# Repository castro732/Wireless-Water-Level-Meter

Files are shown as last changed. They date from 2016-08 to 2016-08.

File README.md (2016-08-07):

#Wireless Water Level Meter

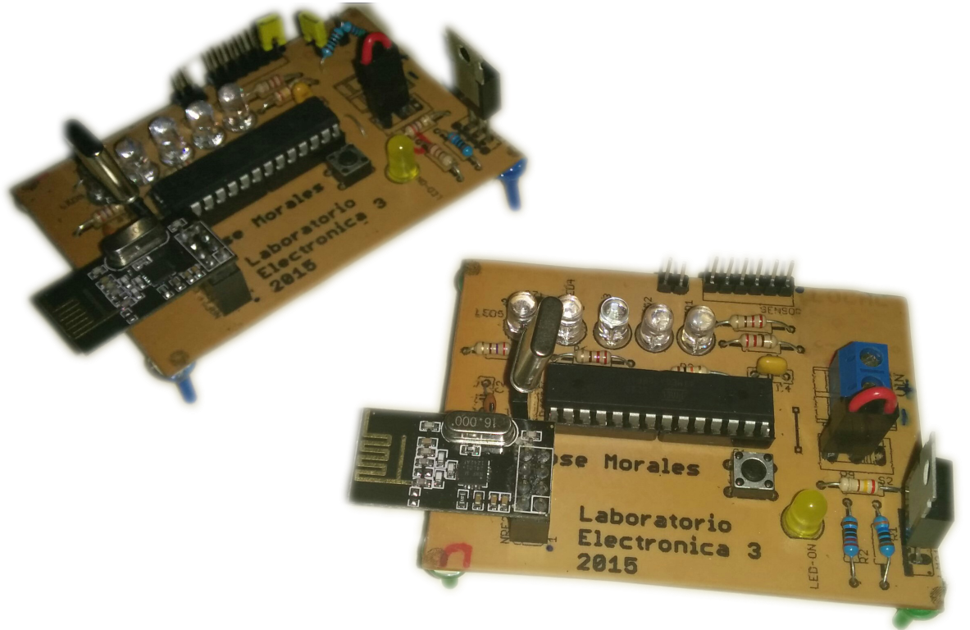
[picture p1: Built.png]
Built modules


##Description

System for measuring the water level in a tank using a current loop (4 mA to 20 mA) wirelessly.

The system consists of 2 modules, a local module and a remote module.
	The local module reads the level of water and transmits it to the remote module (using nRF24L0).
	The remote receives the data and displays it using 5 LEDs, corresponding to the 5 levels of water, from empty to full.

##Features
- Wireless, using nRF24L0.
- Programmed via Arduino using an Atmega328P.
- LEDs indicating the level of water in both modules (local and remote).
- Powered with 5V via screw terminals.
- Programming headers (serial) to facilitate the reprogramming of the microcontrollers.
	- Programs using an Arduino.

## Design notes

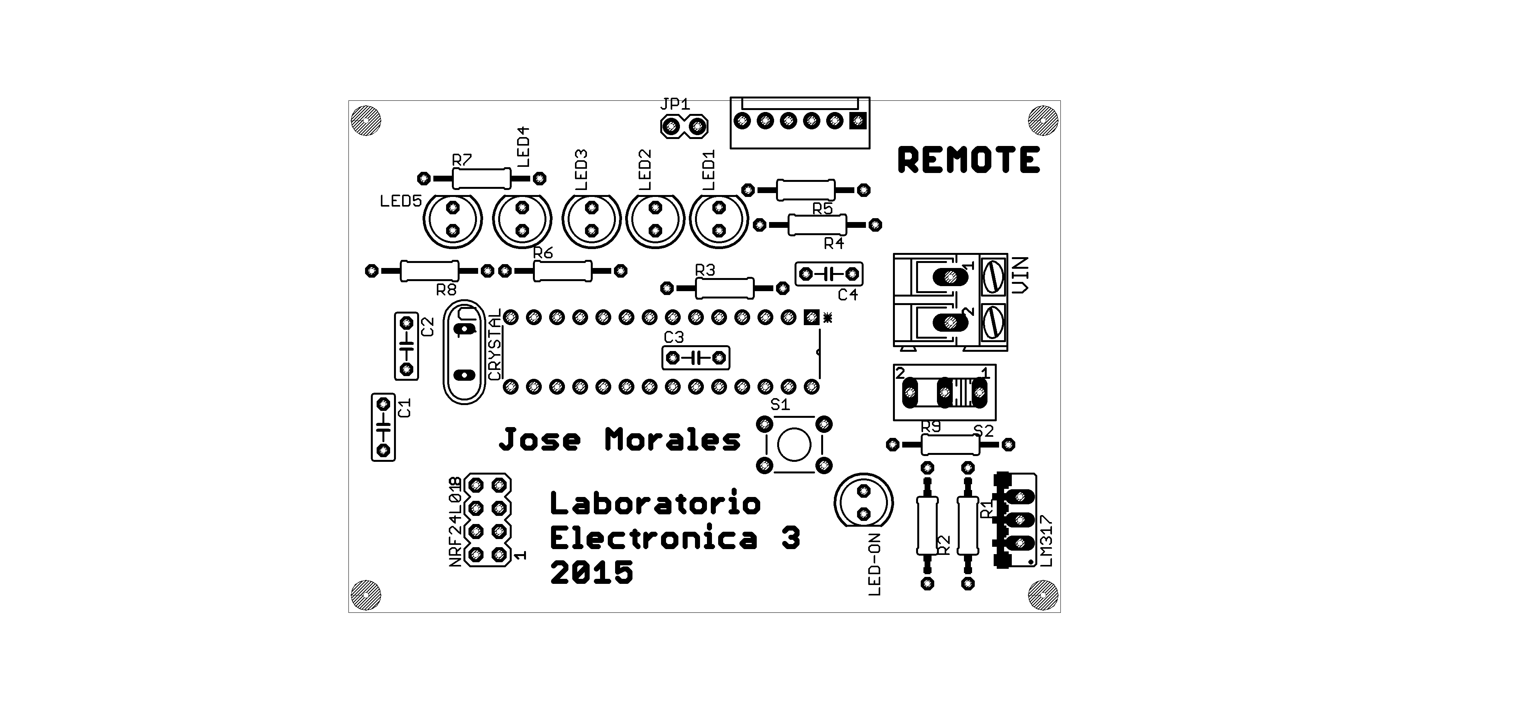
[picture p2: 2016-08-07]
remote_top.png

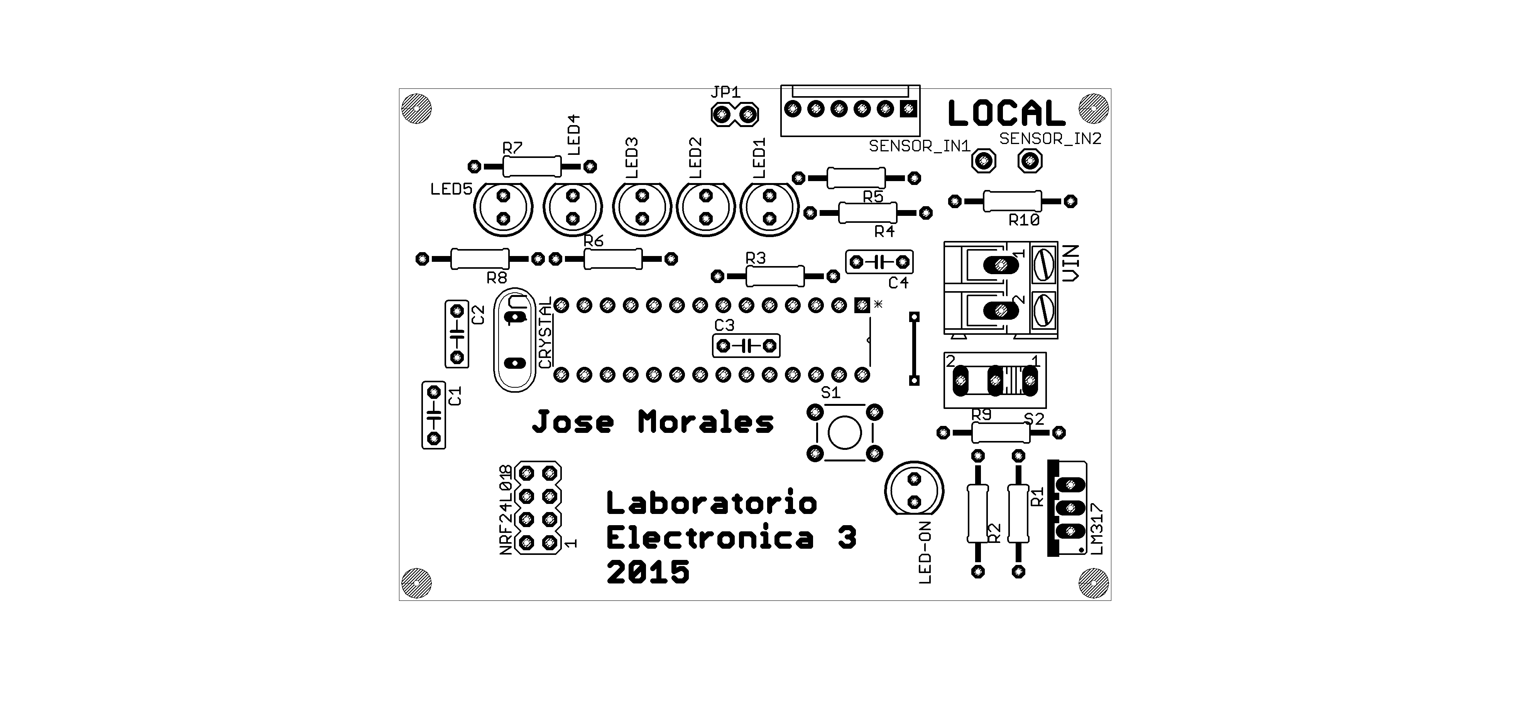
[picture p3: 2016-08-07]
local_top.png

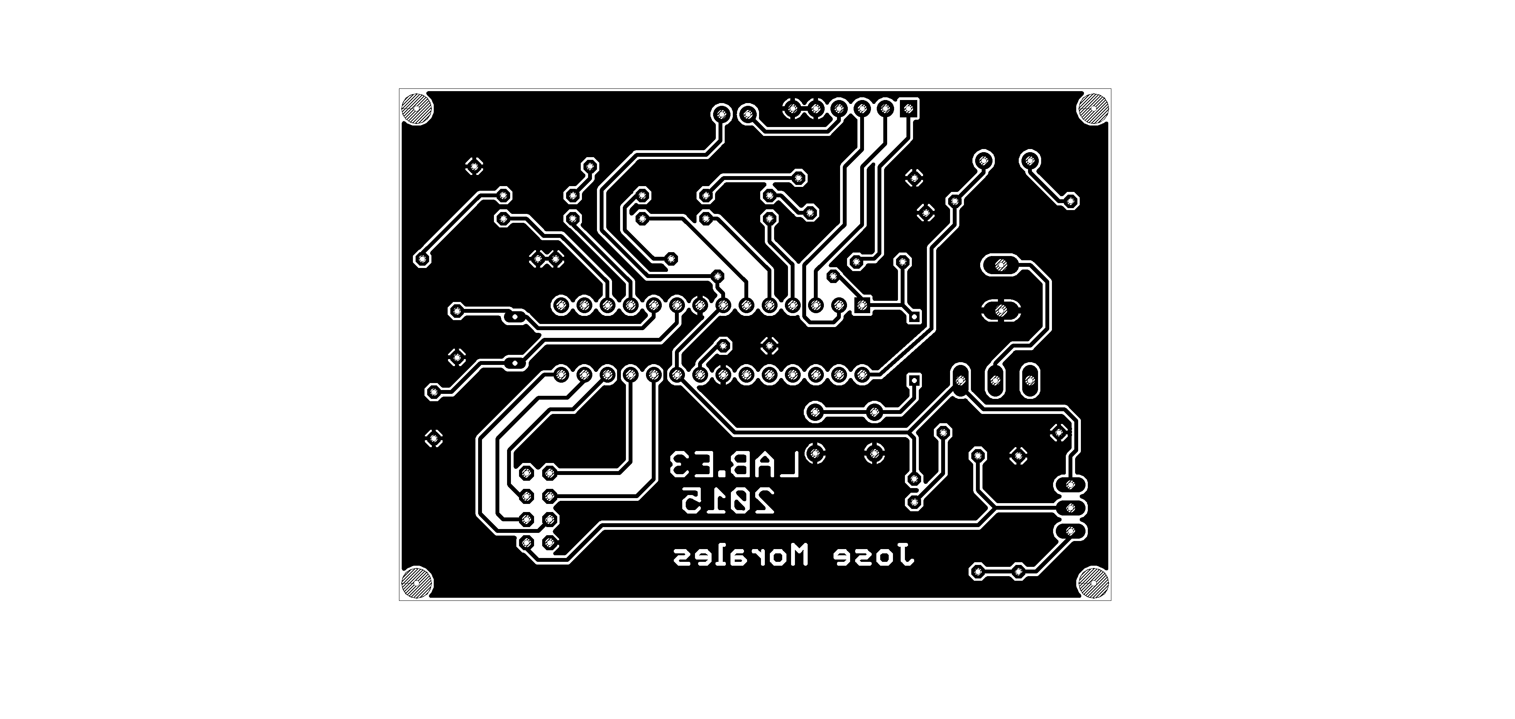
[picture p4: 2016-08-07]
local_bot.png

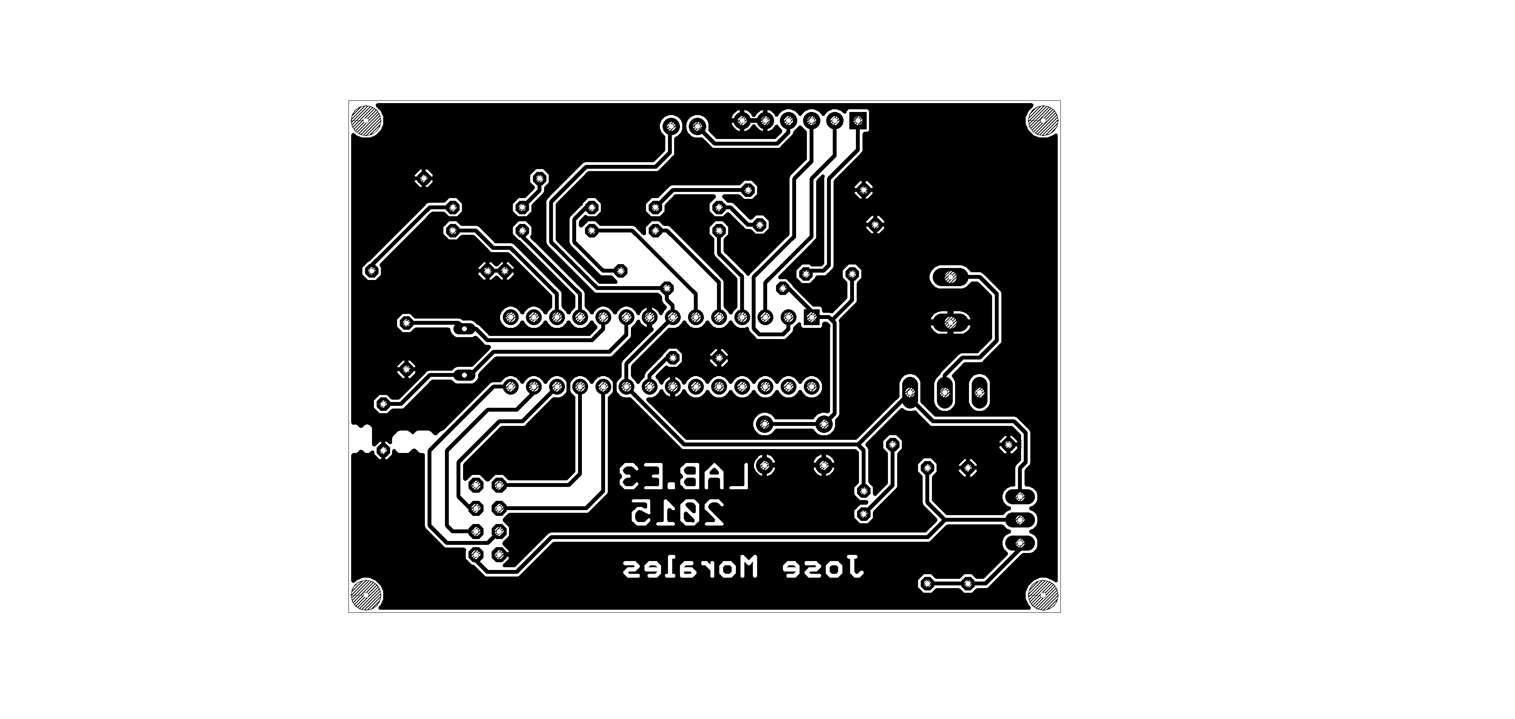
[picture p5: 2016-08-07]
remote_bot.png

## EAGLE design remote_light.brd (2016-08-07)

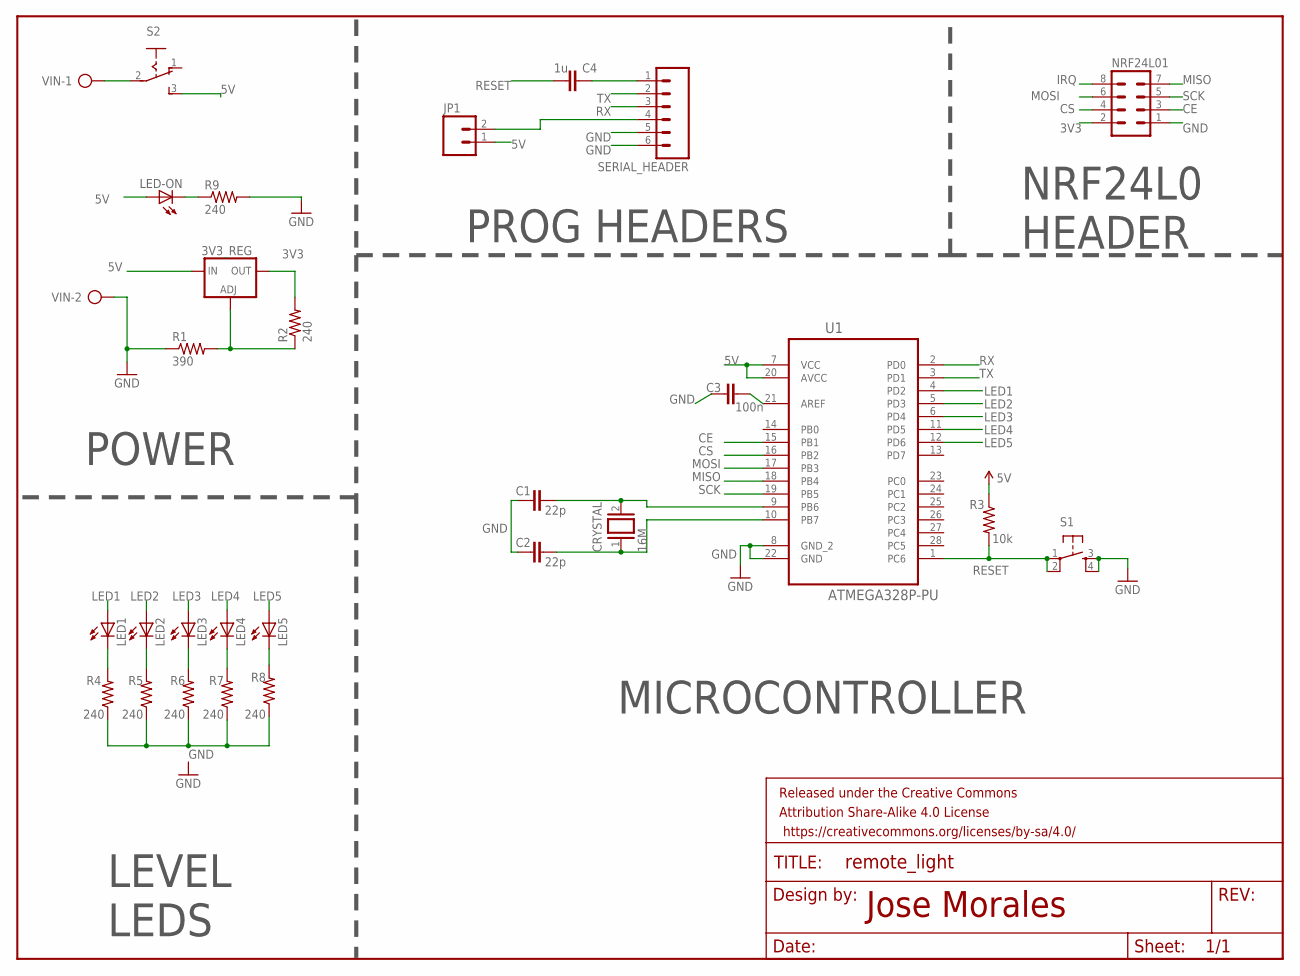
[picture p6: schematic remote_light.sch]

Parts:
C1, C2: 22p; C050-025X075
C3: 100n; C050-025X075
C4: 1u; C050-025X075
CRYSTAL: 16M; QS
FRAME11: FRAME-LETTER; CREATIVE_COMMONS
JP1: M02LOCK; 1X02_LOCK
LED1, LED2, LED3, LED4, LED5: LED5MM
LED-ON: LED5MM
LM317: 3V3_REG; 317TS
NRF24L01: MA04-2
R1: 390; 0207/12
R2, R4, R5, R6, R7, R8, R9: 240; 0207/12
R3: 10k; 0207/12
S1: TAC_SWITCHPTH; TACTILE-PTH
S2: 255SB
SERIAL_HEADER: M06POLAR; MOLEX-1X6
U1: ATMEGA328P-PU; DIP254P762X457-28
VIN: AK300/2

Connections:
3V3: LM317.2 (OUT), NRF24L01.2, R2.2
5V: JP1.1, LED-ON.A, LM317.3 (IN), R3.1, S2.3 (S), U1.7 (VCC), U1.20 (AVCC)
CE: NRF24L01.3, U1.15 (PB1)
CS: NRF24L01.4, U1.16 (PB2)
GND: C1.2, C2.2, C3.2, NRF24L01.1, R1.1, R4.1, R5.1, R6.1, R7.1, R8.1, R9.2, S1.3, S1.4, SERIAL_HEADER.5, SERIAL_HEADER.6, U1.8 (GND_2), U1.22 (GND), VIN.2
IRQ: NRF24L01.8
LED1: LED1.A, U1.4 (PD2)
LED2: LED2.A, U1.5 (PD3)
LED3: LED3.A, U1.6 (PD4)
LED4: LED4.A, U1.11 (PD5)
LED5: LED5.A, U1.12 (PD6)
MISO: NRF24L01.7, U1.18 (PB4)
MOSI: NRF24L01.6, U1.17 (PB3)
unnamed: LM317.1 (ADJ), R1.2, R2.1
unnamed: C1.1, CRYSTAL.2, U1.9 (PB6)
unnamed: LED1.K (C), R4.2
unnamed: LED-ON.K (C), R9.1
unnamed: C2.1, CRYSTAL.1, U1.10 (PB7)
unnamed: LED2.K (C), R5.2
unnamed: LED3.K (C), R6.2
unnamed: LED4.K (C), R7.2
unnamed: LED5.K (C), R8.2
unnamed: C3.1, U1.21 (AREF)
unnamed: C4.2, SERIAL_HEADER.1
unnamed: S2.2, VIN.1
unnamed: JP1.2, SERIAL_HEADER.4
RESET: C4.1, R3.2, S1.1, S1.2, U1.1 (PC6)
RX: SERIAL_HEADER.3, U1.2 (PD0)
SCK: NRF24L01.5, U1.19 (PB5)
TX: SERIAL_HEADER.2, U1.3 (PD1)

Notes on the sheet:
Jose Morales
POWER
PROG HEADERS
NRF24L0 HEADER
LEVEL LEDS
MICROCONTROLLER

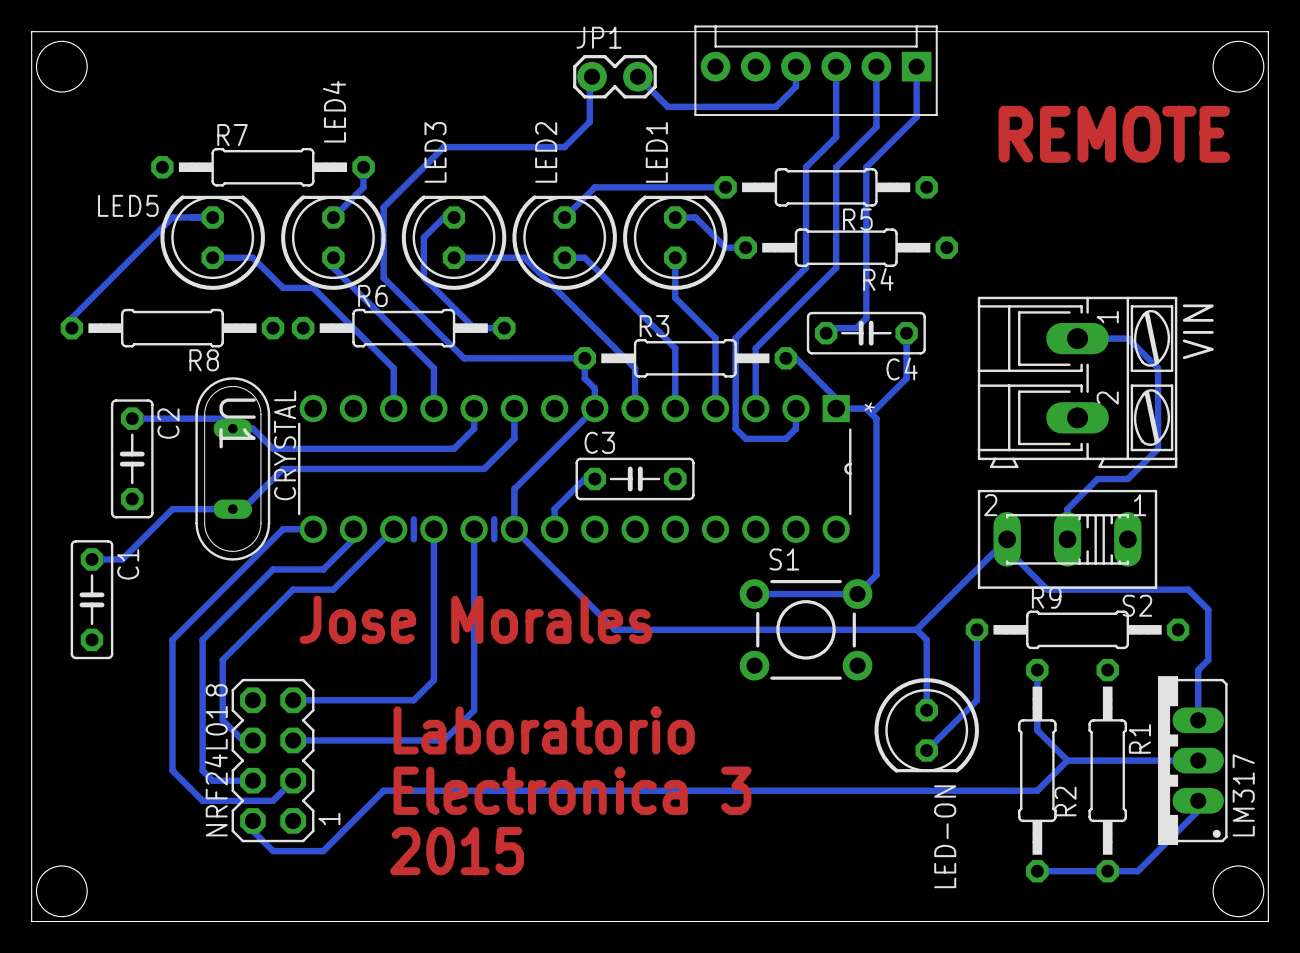
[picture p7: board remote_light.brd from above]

Board: 2 copper layers, 78.1 x 56.2 mm, 29 parts (0 on the bottom side), 29 nets.

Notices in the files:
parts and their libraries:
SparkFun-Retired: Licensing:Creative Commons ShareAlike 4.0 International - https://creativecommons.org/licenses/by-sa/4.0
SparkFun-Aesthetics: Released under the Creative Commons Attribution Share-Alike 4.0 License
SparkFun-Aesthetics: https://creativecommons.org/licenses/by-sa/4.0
